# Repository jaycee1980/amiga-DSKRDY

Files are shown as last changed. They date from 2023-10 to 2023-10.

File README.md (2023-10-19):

# amiga-DSKRDY
This is a small mod board that will provide a DSKRDY signal for drives which don't have one - commonly the case with "PC" disk drives.
Often there are modifications out there which claim to provide a !DSKRDY signal, but they are not actually proper !DSKRDY signals... this can cause issues with some disk routines and will show up as an issue in Amiga Test Kit, for example.

According to the Amiga spec, one should wait either 500ms OR for !DSKRDY to asset, after turning on the drive motor. Many trackloaders on the Amiga simply wait for !DSKRDY to be asserted, and will hang when it never happens. A good example of this is the Escom Amigas which shipped with a modified mainboard, which only diverted the !DSKCHG signal to the correct pin. The Amiga OS itself seems to always use a 500ms wait, so it is not affected by the lack of !DSKRDY.

As we don't have a real !DSKRDY signal to work from, the circuit works by simply asserting !DSKRDY roughly 500ms after !MTR and !SEL are asserted. It is designed onto a small 15x20mm PCB, which can be stuck to the bottom of a floppy drive and wires run to appropriate pads during modification.

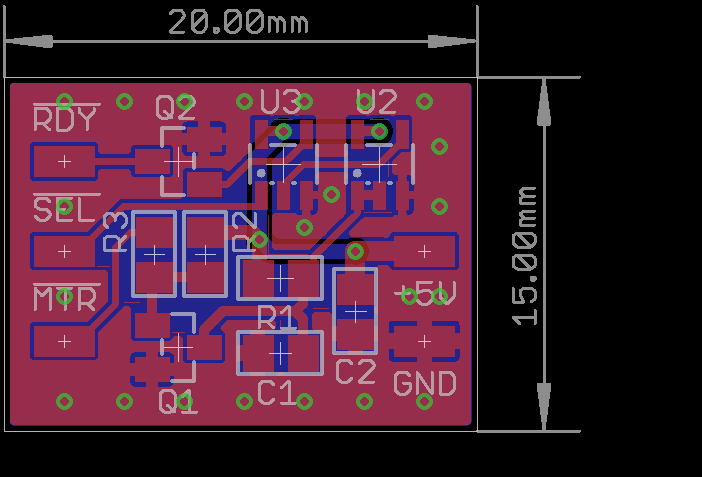
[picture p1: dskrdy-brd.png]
A preview image of the board


## Whats in this repository

The schematic and board design are available, and were made with CadSoft EAGLE (burn in hell, Autodesk). 
There is also a PDF of the schematic.

The "gerber" folder contains suitable Gerber files for having the PCB manufactured. Any good PCB manufacturer should be able to do this - I personally use [JLCPCB](https://jlcpcb.com)

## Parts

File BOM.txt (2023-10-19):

Ref		Description			Digikey PN
R1		Resistor 470K SMD 0805		738-RMCF0805FT470KCT-ND
R2		Resistor 100K SMD 0805		RMCF0805FT100KCT-ND
R3		Resistor 1K SMD 0805		RMCF0805FT1K00CT-ND
C1		Capacitor 2u2 X7R SMD 0805	399-C0805C225J4REC7800CT-ND
C2		Capacitor 100nF X7R SMD 0805	399-C0805C104M5RAC7800CT-ND
U2,U3		74LVC1G132DBV SOT-23-5		296-17888-1-ND
Q1,Q2		2N7002/BSS138 SOT-23-3		2N7002-FDICT-ND

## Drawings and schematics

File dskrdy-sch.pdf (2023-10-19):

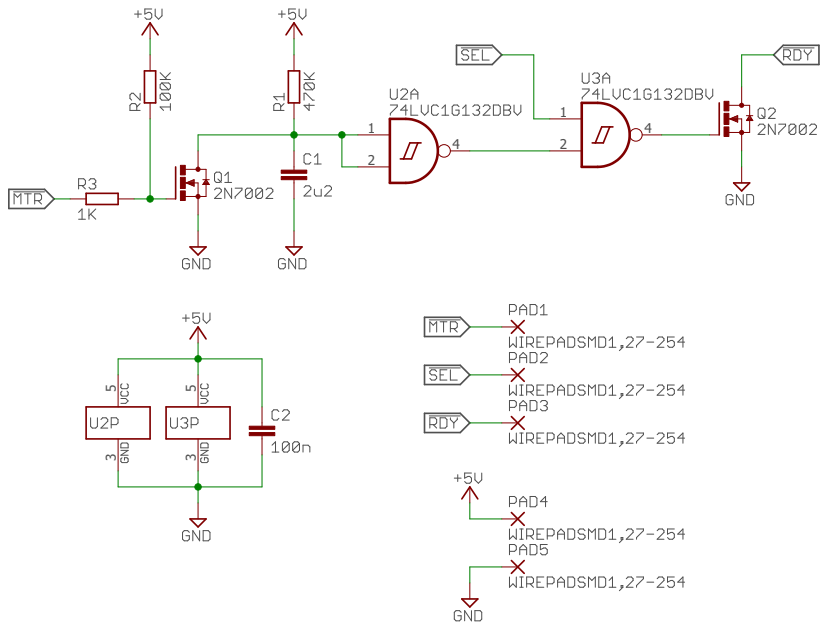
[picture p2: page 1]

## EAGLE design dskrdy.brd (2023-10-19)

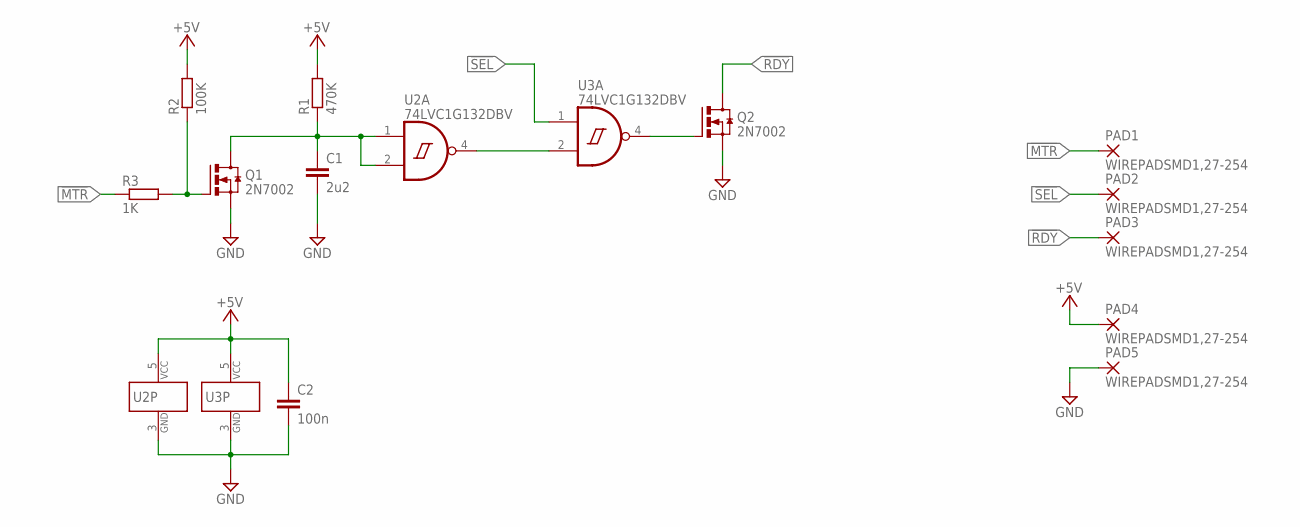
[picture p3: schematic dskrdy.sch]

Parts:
C1: 2u2; C0805
C2: 100n; C0805
PAD1, PAD2, PAD3, PAD4, PAD5: WIREPADSMD1,27-254; SMD1,27-2,54
Q1, Q2: 2N7002; SOT23
R1: 470K; R0805
R2: 100K; R0805
R3: 1K; R0805
U2, U3: 74LVC1G132DBV; SOT23-5

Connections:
!MTR: PAD1.1, R3.1
!RDY: PAD3.1, Q2.3 (D)
!SEL: PAD2.1, U3.1 (I0)
+5V: C2.1, PAD4.1, R1.2, R2.2, U2.5 (VCC), U3.5 (VCC)
GND: C1.2, C2.2, PAD5.1, Q1.2 (S), Q2.2 (S), U2.3 (GND), U3.3 (GND)
unnamed: Q1.1 (G), R2.1, R3.2
unnamed: C1.1, Q1.3 (D), R1.1, U2.1 (I0), U2.2 (I1)
unnamed: Q2.1 (G), U3.4 (O)
unnamed: U2.4 (O), U3.2 (I1)

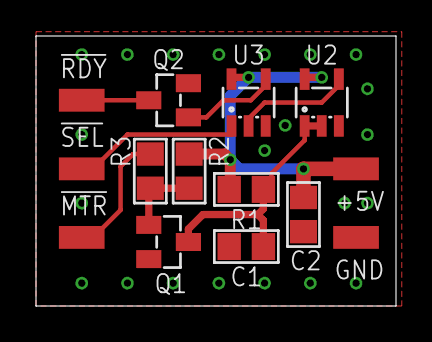
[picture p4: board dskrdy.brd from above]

Board: 2 copper layers, 20.0 x 15.0 mm, 14 parts (0 on the bottom side), 9 nets.

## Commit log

2023-10-19 Added BOM
2023-10-19 More readable PDF schematic
